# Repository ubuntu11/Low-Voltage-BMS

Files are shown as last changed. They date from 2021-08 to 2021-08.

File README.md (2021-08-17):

# Low Voltage Battery Management System with AFE(BQ76920) and Microcontroller (TM4C123GH6PM)
This is a hardware and software development of a low voltage battery management syetem, which is mainly designed for our autonomous BEV and self-driving car. However, it could also be applied to other electric devices which need an monitoring system for low voltage battery.

**LV-BMS version 1 PCB:**
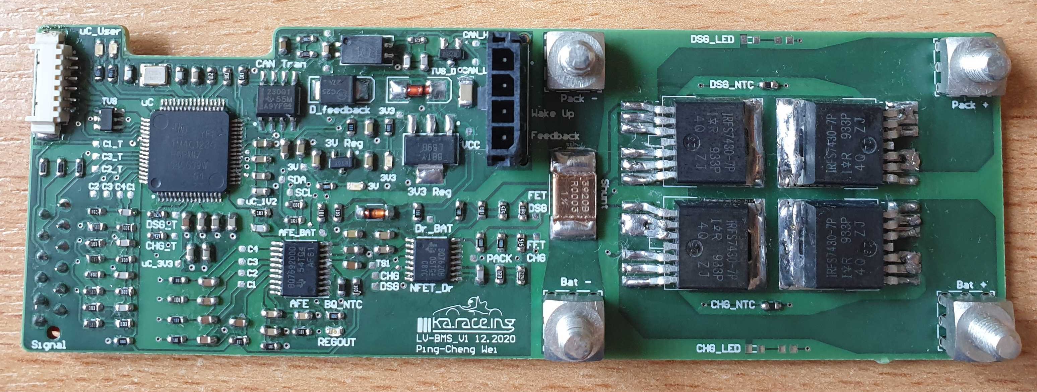
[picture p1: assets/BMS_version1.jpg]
LV-BMS version 1 PCB


The repository includes:
* The Altium PCB design of LV-BMS with either low-side MOSFET switch control(version 2) or high-side(version 3).
* Source code for the microcontroller based on C++, which is compatible for all version(1~3) design, and is written and exploited in Code Composer Studio.
* Texas Instruments TivaWare Peripheral Driver Library for the control of microcontroller. [datasheet](https://www.ti.com/lit/ug/spmu298e/spmu298e.pdf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)

## Table Of Contents
* [Concept and Functionality of the LV-BMS](https://github.com/PingCheng-Wei/Low-Voltage-BMS#concept-and-functionality-of-the-lv-bms)
* [Development of Hardware Part](https://github.com/PingCheng-Wei/Low-Voltage-BMS#development-of-hardware-part)
    * [Components & Datasheets](https://github.com/PingCheng-Wei/Low-Voltage-BMS#components--datasheets)
    * [Explaination of the Functionality in each Part](https://github.com/PingCheng-Wei/Low-Voltage-BMS#explaination-of-the-functionality-in-each-part)
        * [Analog Front End](https://github.com/PingCheng-Wei/Low-Voltage-BMS#analog-front-end-afe)
        * [I2C Communication](https://github.com/PingCheng-Wei/Low-Voltage-BMS#i2c-communication)
        * [FET Driver](https://github.com/PingCheng-Wei/Low-Voltage-BMS#fet-driver)
        * [Analog to Digital Converter](https://github.com/PingCheng-Wei/Low-Voltage-BMS#analog-to-digital-converter-adc)
    * [Altium PCB Design](https://github.com/PingCheng-Wei/Low-Voltage-BMS#altium-pcb-design)
* [Concept of Software Part](https://github.com/PingCheng-Wei/Low-Voltage-BMS#concept-of-software-part)
    * [Enviroment and Library](https://github.com/PingCheng-Wei/Low-Voltage-BMS#enviroment-and-library-datasheet)
* [Installation](https://github.com/PingCheng-Wei/Low-Voltage-BMS#installation)

# Concept and Functionality of the LV-BMS
The main idea that we need a battery management system is that lithium battery has a higher energy density, higher efficiency and lighter weight in comparison with other art of battery such as LiFePo4, which is crucial in our case to gain better performence, but it could also be life-threatening when something goes wrong. Therefore, we need a monitoring system, BMS, to keep supervising the status of the lithium battery stack during the execution of whole system and take defensive action if it is needed. The status at here means the `voltages`, `current` and `temperatures` of the battery stack. To be more specific, voltages could be the `cell voltages` as well as the `entire voltage` and current is the `entire current` that flows out the battery stack and temperatures could be the `cell temperatures` as well as the `MOSFETs' temperatures`. 

BMS monitor these three status to make sure they are all operating in the acceptable range. if not, then BMS will cut off the power supply of the whole system (LV-Battery) by switching the MOSFETs to off so that no further damage could happen and if the stutas are back to normal again, then BMS will turn on the power suppy again.

# Development of Hardware Part
The general structure of the hardware PCB design is based on the following functional parts:

* `Analog Front End (AFE)`, which is mainly responsible for collecting the parameters of the battery pack such as voltages, current as well as temperatures by using internal ADC measures. It could also control the current between the cells in order to avoid overloading and underloading, which is called cell-balancing. At here we pick [BQ76920](https://www.ti.com/lit/ds/symlink/bq76920.pdf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) from TI as our AFE since it has not only all the basic features that we need but also some other extra features e.g. hardware protection features, charge/discharge low-side NCH FET drivers, alert interrupt to host microcontroller, simple I2C compatible interface (CRC option)

* `Inter-Integrated Circuit (I2C) Interface`, which is really crucial to realize the communication between our host microcontroller (uC), `TM4C123GH6PM`, and AFE ,`BQ76920`. Through the I2C communication, uC can read value from AFE register, send commmed to AFE or even write value into the register in AFE and AFE can also sent alert to uC so that uC could take an action to deal with the errors

* `Microcontroller (uC)`, which is like the brain of the system and where we flash our code into in order to realize all the functions that we need. Here is `TM4C123GH6PM` chosen as our uC because it has lots of features to utilize and there is also a compatible [Peripheral Driver Library](https://www.ti.com/lit/ug/spmu298e/spmu298e.pdf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) on hand.

* `FET Driver`, which is needed if we want to have a high-side switch control feature according to our AFE, BQ76920, and provides the advantages of avoiding ground disconnection in the system and continuous communication between the battery pack and host system. Here [BQ76200](https://www.ti.com/lit/ds/symlink/bq76200.pdf?ts=1629016585303&ref_url=https%253A%252F%252Fwww.google.com%252F) is chosen as it is directly competible and circuit design is also provide in both [BQ76200](https://www.ti.com/lit/ds/symlink/bq76200.pdf?ts=1629016585303&ref_url=https%253A%252F%252Fwww.google.com%252F) and [BQ76920](https://www.ti.com/lit/ds/symlink/bq76920.pdf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) datasheet.

    Here is an overview of how BQ and uC structured:
    
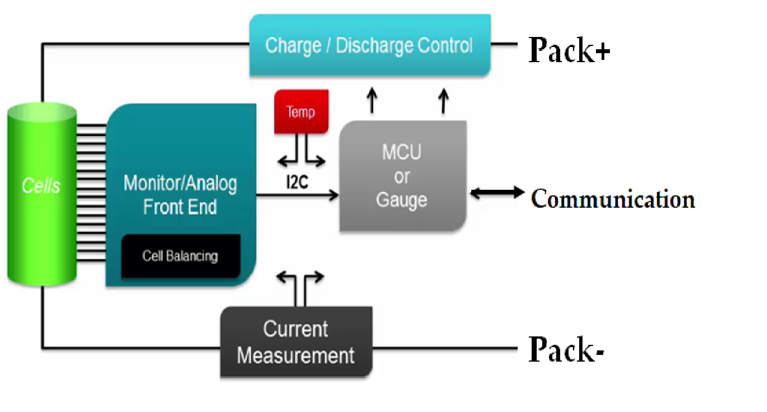
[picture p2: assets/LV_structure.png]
overview of BQ-chip
    

Other features that we need for our autonomous BEV and self-driving car:
* `CAN Bus system`, which is a communication system between our uC and centeral `main control unit (MCU)` in our cars so that MCU could know what is going on right now in LV-system and whether every thing is fine. For some cases, MCU could even take some preventative steps to protect the car if something in LV-system goes wrong.
* `Analog to digital converter (ADC) in uC`, which is exploited for more temperatures monitoring such as Battery stack temperatures and MOSFETs' temperatures.

## Components & Datasheets
You could find all the components and their footprints that are utilized on the PCB in the [Bill of Materials (BOM)](https://github.com/PingCheng-Wei/Low-Voltage-BMS/blob/main/assets/BOM_LV_21E.xlsx). Here we just list the most important components:

* Microcontroller: [TM4C123GH6PM](https://www.ti.com/lit/ds/spms376e/spms376e.pdf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)
* Analog Front End: [BQ76920](https://www.ti.com/lit/ds/symlink/bq76920.pdf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) without CRC
* FET Driver: [BQ76200](https://www.ti.com/lit/ds/symlink/bq76200.pdf?ts=1629016585303&ref_url=https%253A%252F%252Fwww.google.com%252F)
* MOSFETs: [AUIRFS8409-7P](https://www.infineon.com/dgdl/auirfs8409-7p.pdf?fileId=5546d462533600a4015355b745e314f0)
* 3.3V CAN Bus Transceivers: [SN65HVD230](https://www.ti.com/lit/ds/symlink/sn65hvd230.pdf?ts=1628607753622)

Other useful datasheets for more understanding of the circuit design:
* BQ relevant:
    * [bq76200 Beyond the Simple Application Schematic](https://www.ti.com/lit/an/slua794/slua794.pdf?ts=1629017183044&ref_url=https%253A%252F%252Fwww.google.com%252F)
    * [FET Configurations for the bq76200 High-Side N-Channel FET Driver](https://www.ti.com/lit/an/slva729a/slva729a.pdf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)
    * [bq769x0 Family Top 10 Design Considerations](https://www.ti.com/lit/an/slua749a/slua749a.pdf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)
    * [10s battery monitoring, balancing, and comp protection, 50A discharge ref design](https://www.ti.com/lit/ug/tiduar8c/tiduar8c.pdf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)
    * [bq769x0 BMS Configurations for Cordless Appliances](https://www.ti.com/lit/an/slua810/slua810.pdf?ts=1628994785378)

* I2C relevant:
    * [Understanding the I2C Bus](https://www.ti.com/lit/an/slva704/slva704.pdf?ts=1629009658472&ref_url=https%253A%252F%252Fwww.google.com%252F)
    * [I2C Communication Sample Code for the bq76940 with a CRC Option Based on the MSP430G2553](https://www.ti.com/lit/an/slva626b/slva626b.pdf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)

* Microcontroller relevant:
    * [MCU_tm4c123gh6pm](https://www.ti.com/lit/ds/spms376e/spms376e.pdf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)
    * [TivaWare Peripheral Driver Library Users's Guide](https://www.ti.com/lit/ug/spmu298e/spmu298e.pdf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)

## Explaination of the Functionality in each Part
### Analog Front End (AFE)
As described above, we use an AFE, BQ76920, to realize the parameters monitoring and MOSFETs control. Here we would like to explain more about the funtionality behind `BQ76920`. It is also helpful to go deep into datasheet as it not only provides you a better overview of hardware but also better understanding of the algorithm in software code.

BQ76920 is a pre-programmed chips that already has the function like voltages, current and temperatures measurement and it would automatically keep monitoring/update the value in a certain amount of time. If something goes wrong, the internal system status will be set to bit 0 and automatically disable the charge and discharge control (CHG & DSG Pins set to 0). Therefore, in order to use BQ76920, it is rather important to grasp the concept of how to let microcontroller communicate with the BQ's register and control the BQ's status through I2C than understand how internal measurement works. here is an important system status of BQ76920 in register:
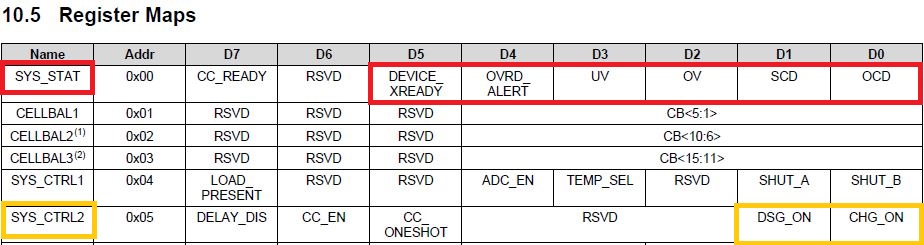
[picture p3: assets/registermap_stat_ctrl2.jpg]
status in register map


Take cell voltages measurement for example, `it update the cell voltages at a rate of 250 ms` and store the value inside its register for other functions utiliztion such as overvoltage and undervoltage check. This means that if BQ76920 updates the voltage and finds out they are out of the limit range, it will internally set the corresponding system status to 0 (means error) and since system status are not all 1, it will then automatically turn off the power supply by shuting down the CHG or DSG Pin to bit 0, which is bit 1 (means on) when everything is fine, and send a alert signal to our microcontroller. This all happen in BQ internally by itself. Thus, you might wonder why we need a microcontroller then if everything works internally. The reason is that we need a microcontroller to clear the alert/error bit. By that it means that microcontroller will keep demanding the BQ to update its system status, in this case keep measuring the cell voltages, and until the voltages are back into acceptable range microcontroller can then successfully clear the alert/error bit and BQ would then allow the charge or discharge control by setting CHG or DSG Pin to bit 1.

### I2C Communication
In order to grasp the deep understanding of how I2C works, it is highly recommanded that you go through and deep into this article "[Understanding the I2C Bus](https://www.ti.com/lit/an/slva704/slva704.pdf?ts=1629009658472&ref_url=https%253A%252F%252Fwww.google.com%252F)". In the article you should understand how I2C recognize the start as well as the end bit from SCL (Serial Clock) & SDA (Serial Data) and how the signals are read. Here we would like to show some I2C signal from Oscilloscope:

* overview:
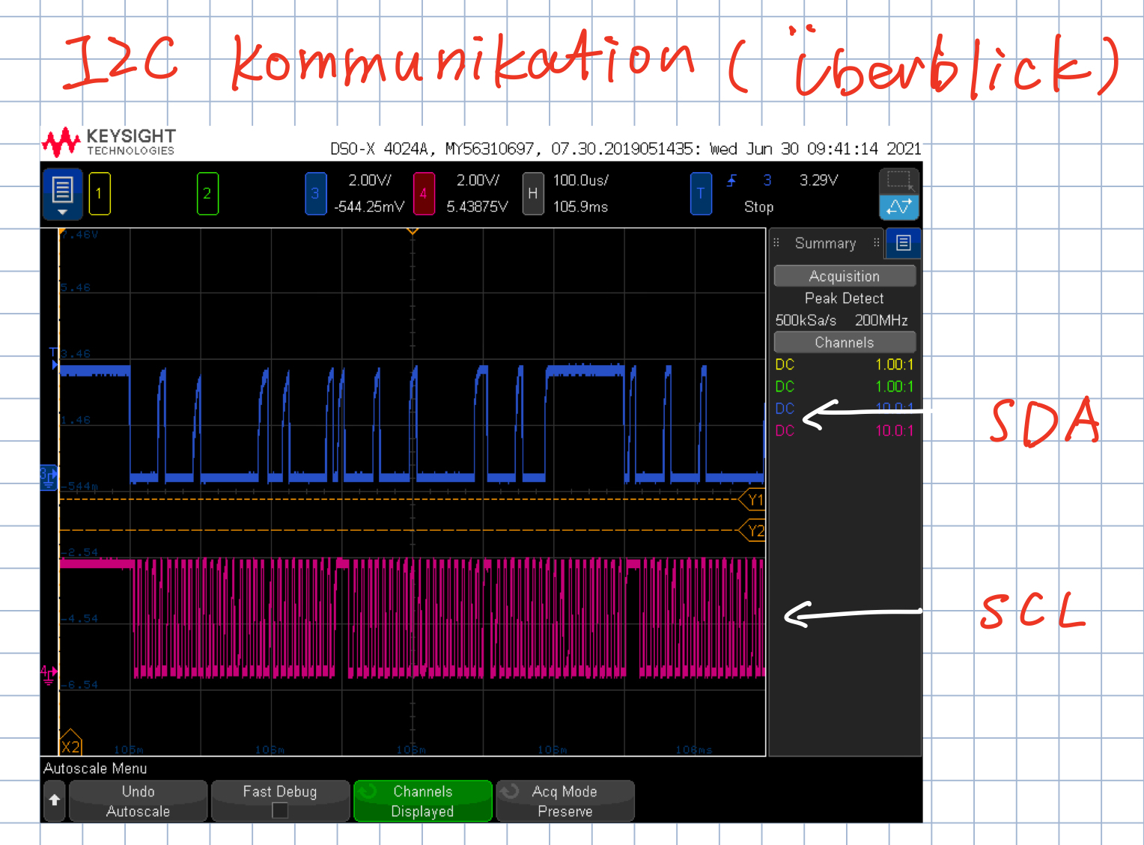
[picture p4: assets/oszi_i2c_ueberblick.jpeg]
oszi_i2c_overview
    
* I2C Signal:
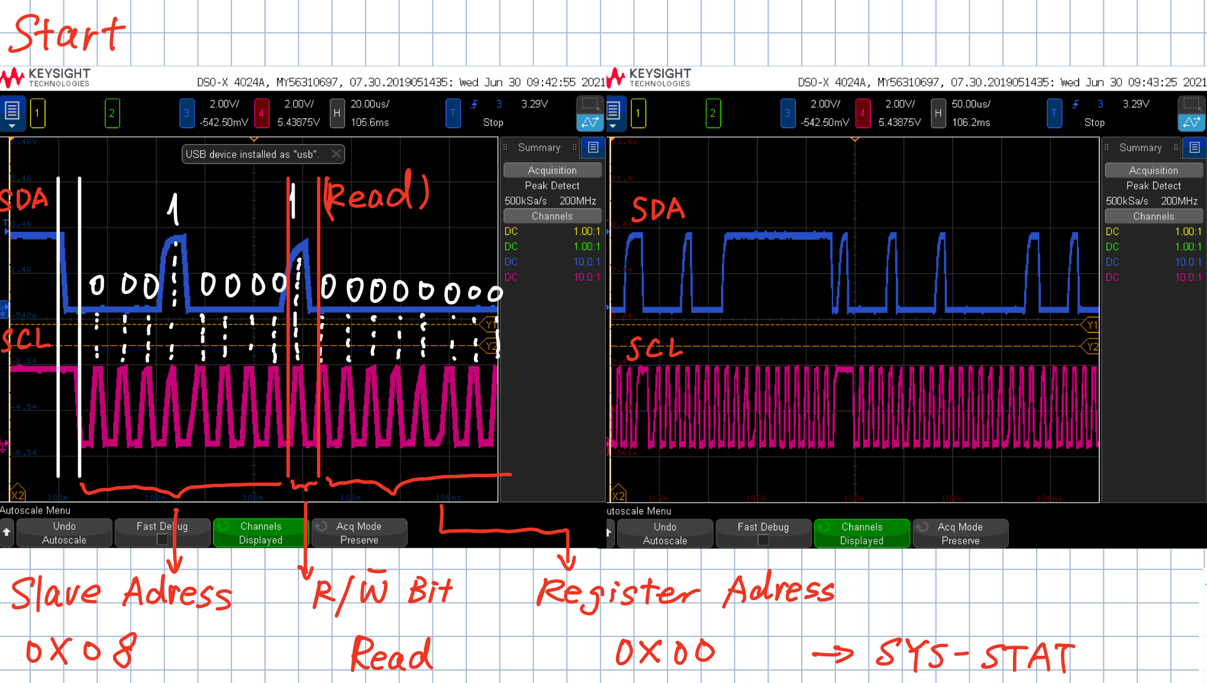
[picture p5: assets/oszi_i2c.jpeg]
oszi_i2c_signal
    

### FET Driver
As mentioned above, BQ76920 itself only support the low-side switch feature. However, in some cases it would benefit more if we would able to use high-side switch. That is why we need a FET Driver to convert the signal of CHG/DSG from BQ76920 to higher voltage. The idea behind [BQ76200](https://www.ti.com/lit/ds/symlink/bq76200.pdf?ts=1629016585303&ref_url=https%253A%252F%252Fwww.google.com%252F) is using a `charge pump capacitor`, which works like an extra small battery connected in series with low-voltage battery, as you could see in the circuit example `between the VDDCP and BAT pins`. During the operation the charge pump capacitor will keep charging and discharging process to store and release the energy. By doing so we could raise our gate-voltage of MOSFETs to surpass the source-voltage of MOSFETs, which is same as low-voltage battery voltage, and achieve a positive gate-source-voltage to turn on the high-side MOSFETs. 

Here is how the voltage from CHG and DSG changes after the FET driver:
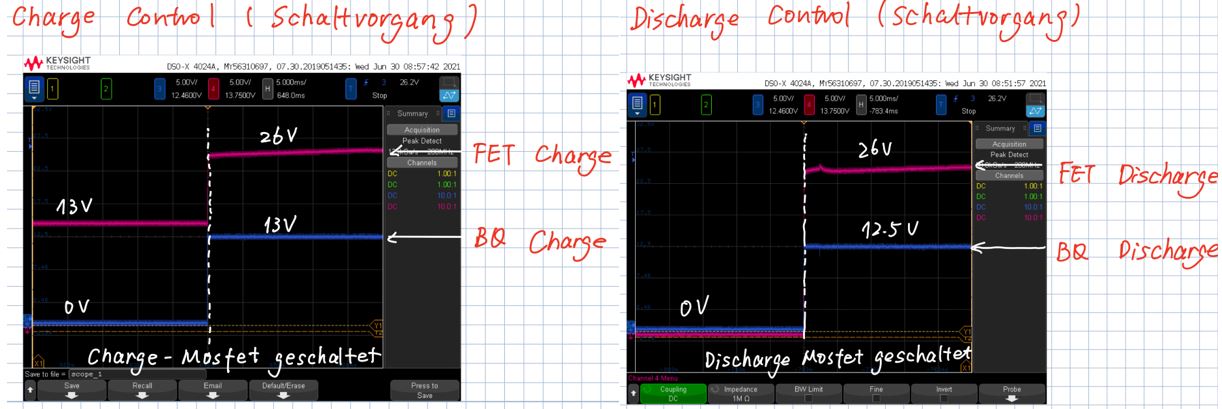
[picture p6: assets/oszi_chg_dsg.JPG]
oszi_chg_dsg


It is also interesting to see the charging and discharging process in charge pump capacitor:
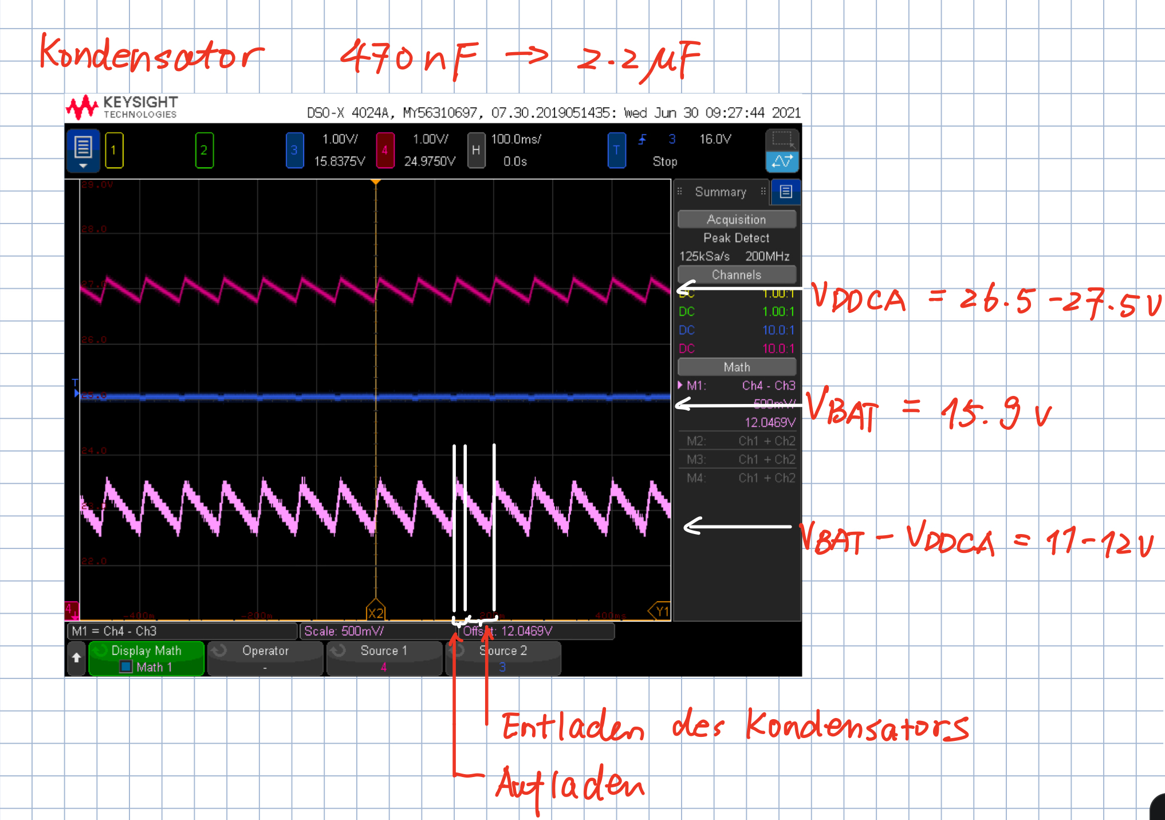
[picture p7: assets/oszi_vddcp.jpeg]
oszi_vddcp


If everything works fine the `gate-source-voltage` of the MOSFETs would looks like this:
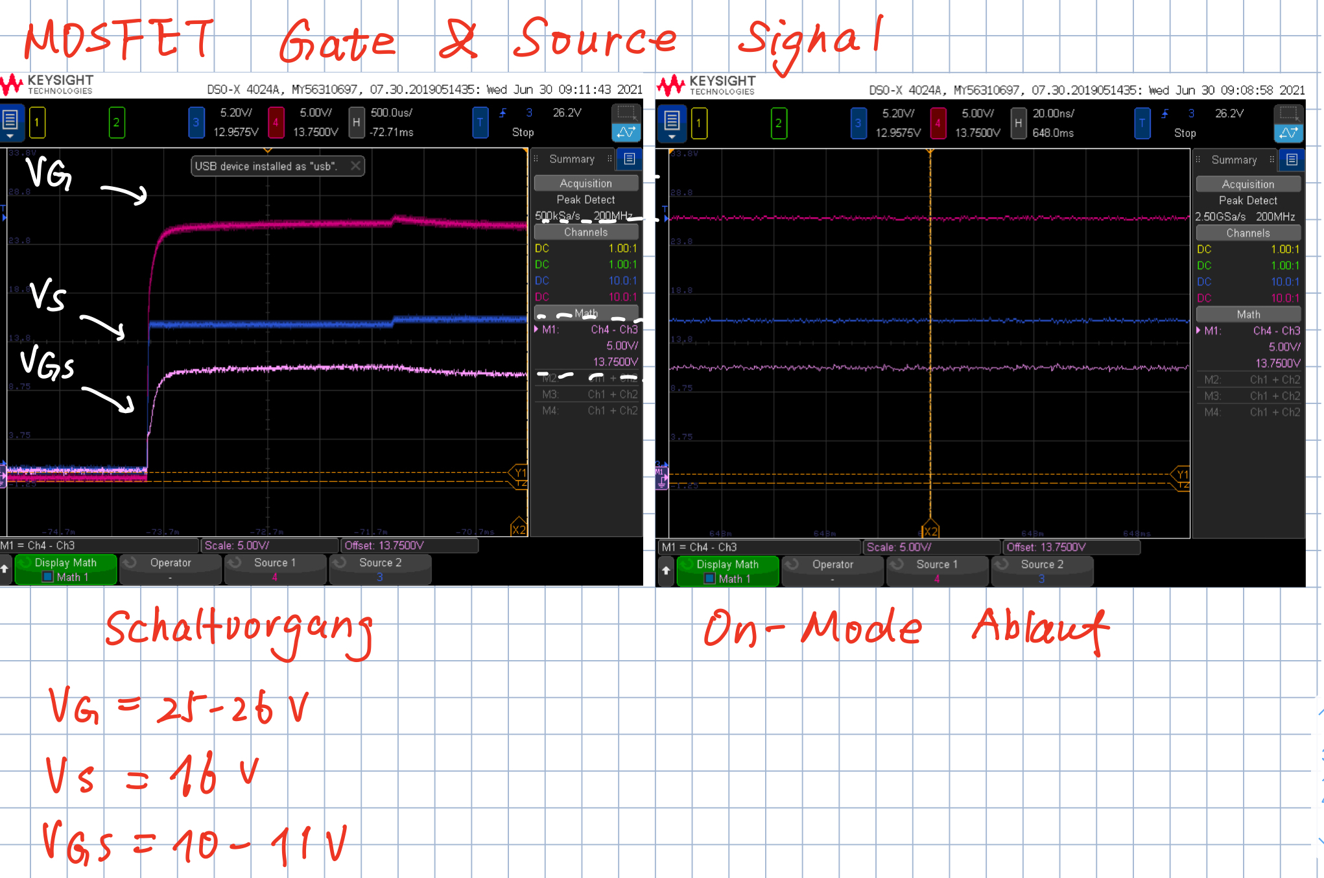
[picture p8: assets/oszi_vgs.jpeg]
oszi_vgs


`Here is the capacity of the charge pump capacitor very critical !!!` If the value is too small, then the capacitor can't store enough energy and it will soon be all released, which leads to just some peaks of higher voltage as the images below show:

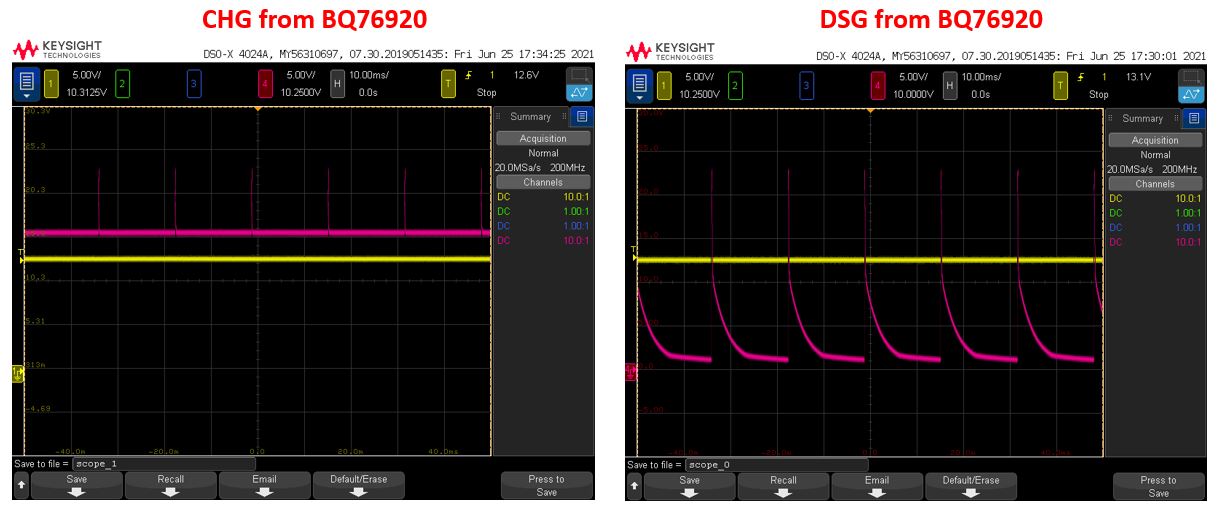
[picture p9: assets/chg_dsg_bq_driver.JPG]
chg_dsg_bq_driver


If the capacity is too big, then the capacitor does not have enough time to reach the needed energy since the charging rate is too low. Therefore, `after several testing we have chosen $2.2 uF$ instead of $470nF$ according to datasheet`.

### Analog to Digital Converter (ADC)
Since the microcontroller can't understand the analog value such as 3.3V or 1A and its internal measurement only send back a bit by bit signal e.g. in a range of 0 ~ 4096 corresponding to 12 bits signal, we need to convert/calculate this bit by bit signal back to the corresponding analog value range and we will recieve the so called digital value. Here is the general equation of ADC:
    
ADC_equation

For example if we have the following situation:
* ADC signal bit length: 12 bits
* Voltage range: 0 ~ 4.3V
* ADC measured value: 3000 

then our converted digital value would be:
    
ADC_calculation

which means the measured ADC valus 3000 is corresponding to 3.15V.

## Altium PCB Design
Generally, we have 4 functional parts: `Microcontroller (TM4C)`, `Analog Front End (BQ76920)`, `FET driver (BQ76200)`, `MOSFETs` for power contro.
We place it in such a way that the analog part, digital part, power part are as separated as possible from each other so that we have cleaner signals. As the image below shown, which is based on LV-BMS version 1, you can see that the polygons are divided into 3:

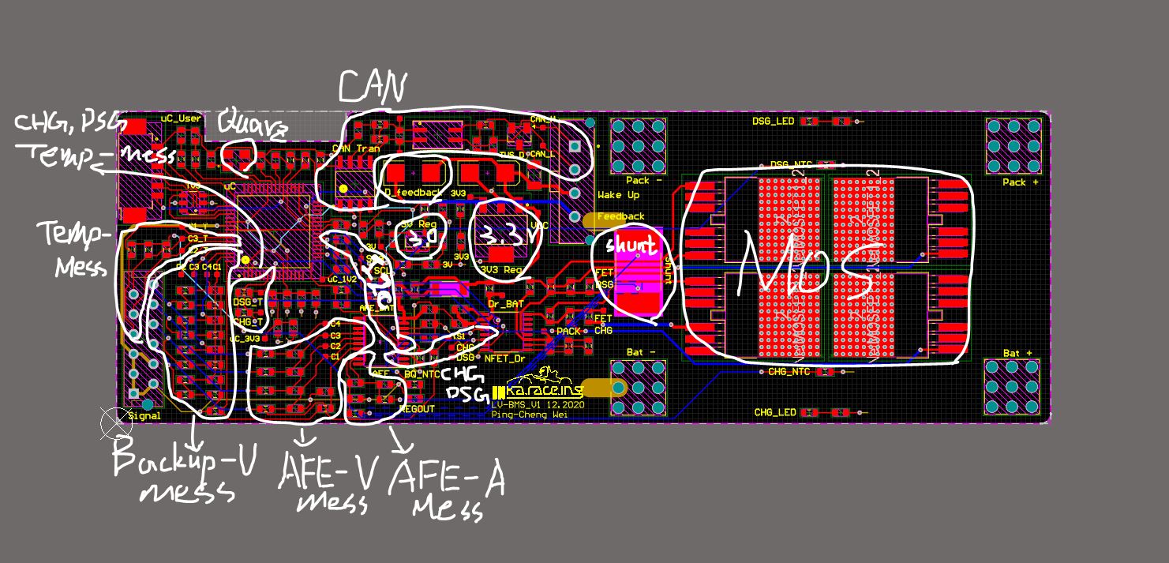
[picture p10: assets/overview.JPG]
overview of PCB design


Polygons and netz distribution based on LV-BMS version 1:
| Net von Polygons | Analog Part  | Digital Part  | Power Part |
| --- | ---  | ---  | --- |
| Top Layer | GND | GND | (komplizierter) |
| GND Layer | GND | GND | GND |
| VCC Layer | V_REF (3.0V) | +3.3V | Bat + |
| Bottom Layer | GND | GND | GND |

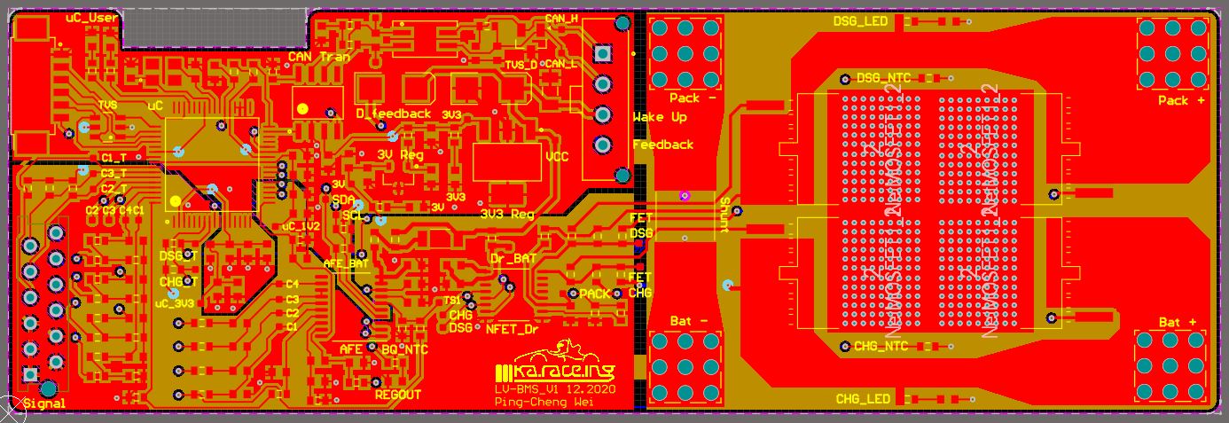
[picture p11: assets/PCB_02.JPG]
Polygons of PCB design


# Concept of Software Part
We have created our header files and source files based on following different functions we needed:

* `ADC`: enable the ADC function in microcontroller and include the convert voltage and temperature functions for monitoring
* `I2C`: create a `bq769x0 class` for AFE (BQ) and enable I2C communication with microcontroller
* `Timer`: create timer interrupt to percisely call a function at a certain rate and percise delay function, which is better then using SysCtlDelay(5000000)
* `GPIO`: General Purpose Input/Output, to enable or activate the pins on microcontroller and set the pin as input or output (3.3V)
* `CANDriver`: create a basic CAN class including basic CAN bus initialization and communication functions like sending and receiving messages
* `TestCAN`: inherit from CANDriver class. This builds the structure of our CAN message in byte level.

The main idea of code is to update BMS status at the rate of $250mS$ to monitor the voltages, current and temperatures. Therefore, we have created a `GlobalBMSUpdate` function and a timer interrupt to percisely call this function at this rate. For our AFE/BQ-chip, we have created a class for it, which has lots of features such as **current status, min/max limit of each status and BQ slave adress** and functions like **I2C communication, set values, get current status values, update status and enable charging/discharging**. By doing so, you could design a LV system with even more BQ-chips by create more BQ objects and don't need to worry about the code being messy as well as confused. However, we just create 1 BQ object as we only need 1 BQ76920 in our case. This BQ class also support other chips in BQ769x0 family, which could monitor more voltages and temperatures. 

Additionaly, we have enabled the ADC function in microcontroller since our microcontroller has lots of features and we want more ADCs to monitor more temperatures and utilize for backup voltages in case BQ is somehow not working.

Overall steps and ideas in main function (main.cpp):
1. Include all libraries and header files we needed
2. Create BMS object as global variable, `BMS`
3. Define global BMS update function, `GlobalBMSUpdate()`, for `TimerBMSUpdatesInterruptBegin()` function
4. Set up system clock & Initialization of all TM4C Systems (GPIO, ADC, Timer, CAN)
    * Set up system clock at 80 MHz
    * By GPIO is mainly focusing on port enabling from TM4C (Port A-F) and also Pin type for FET Driver and LED
    * By ADC are all the necessary settings for ADC measurement such as ADC 1,2 , sample sequence, step configuration, ADC enable
    * Start the `TimerDelayInterruptBegin()` function so that we could have a precise delay for later use
    * Set up the rx_pin, the tx_pin, and the rate for CAN
5. Enable charge pump and pack+ monitor for FET Driver
6. Initialize the I2C/BQ-chip (AFE) from `BMS`
    * `Enable I2C Communication !!!!!`
    * Initialize all the temperature and voltage buffer
    * Boot up BQ-Chip by outputting 3.3V from a GPIO Pin of TM4C for just a short time (around 2ms) ⇒ BQ always need an Activation at first before it starts working (change from SHIP mode to NORMAL mode)
    * Test I2C functionality by trying to write (I2CWriteRegister) something in the register of BQ and checking the equality from reading the register (I2CReadRegister)
        * If communication succeed, enable I2C voltage and temperature ADC readings and switch CC_EN on
    * Initialize and set up the alert interrupt IRS (GPIO_RISING_EDGE interrupt)
    * Get the ADC offset and gain
7. `BMS` system set up
8. Call the `TimerBMSUpdatesInterruptBegin()` function to run the GlobalBMSUpadate, which would enable CHG and DSG simultaneously, in each 250 second
9. Activate the ADC function in uC to read the temperatures
10. check the Temperature status. if too high, then BMS shutdown the battery
11. Send out the message through the CAN bus to let our `Main Control Unit` in car know the status of LV system

_For more information and understanding, explore yourself in the code, which is pretty well commented. The main and biggest part of the code is the I2C part ( [I2C.hpp](https://github.com/PingCheng-Wei/Low-Voltage-BMS/blob/main/Software_Code/LV-BMS_Code/include/I2C.hpp) & [I2C.cpp](https://github.com/PingCheng-Wei/Low-Voltage-BMS/blob/main/Software_Code/LV-BMS_Code/src/I2C.cpp) )_

## Enviroment and Library (datasheet)
* Code written in C++
* Code Composer Studio (CCS) with setting of `TM4C123GH6PM` microcontroller for flashing
* TivaWare Peripheral Driver Library

# Installation 
1. Clone this repository

    if you download this repository directly without any changing, your directory should have the following structure:

    ```
    <dataset root directory (e.g. Low-Voltage-BMS)>/
    assets/
    Hardware_PCB_Design/
        LV-BMS_high-side/
            ...
            LV-BMS_21_V2.PrjPcb
            LV-BMS_V2_21E.PcbDoc
            ...
        LV-BMS_low-side/
            ...
            LV-BMS_21_V3_low-side.PrjPcb
            LV-BMS_V3_21E_low-side.PcbDoc
            ...
    Software_Code/
        LV-BMS_Code/
            ...
        tidriverlib-master/ 
            ...
    ```

    Please keep the Software part structure as it is, otherwise it won't work in CCS unless you change the path to where you put the `tidriverlib-master` !!!

2. Download Altium and activate a licence in order to use it 
    * imoprt all the schematic libraries, PCB libraries and compiled libraries of the conponents from `Component Footprint Import` directory. Please check out online tutorials to see how to import Footprint from integrated libraries (`.IntLib`), schematic libraries (`.SchLib`) and PCB libraries (`.PcbLib`) or check this links: [Working with Integrated Libraries in Altium Designer 2021](https://www.altium.com/documentation/altium-designer/working-with-integrated-libraries-ad?version=17.1), [Working with Integrated Libraries in Altium Designer 2020](https://www.altium.com/documentation/altium-designer/working-with-integrated-libraries-ad)
    
    * Here are some useful links to download and import your own footprint of components you needed
        * [Free Online PCB CAD Library | Ultra Librarian](https://www.ultralibrarian.com/)
        * [Import the downloaded Ultra Librarian files into Altium Designer](https://app.ultralibrarian.com/content/help/?altium_designer.htm)

    * In order to open the PCB project, click the file with  `.PrjPcb` extension. This will automatically open all the schematics and PCBs file which belong to the Project.
        ```
        For instance: LV-BMS_21_V2.PrjPcb
        ```

3. Download Code Composer Studio
    * Set the microcontroller to `TM4C123GH6PM`
    * Make sure the path to the TivaWare Peripheral Driver Library (`tidriverlib-master`) is correctly pointed to in the properties of the project. Right click on the `KIT21_LVBMS_Code` and then go to `Properties`. Do the followings:
        * Go to `CCS Build -> ARM Compiler -> Include Options`
            ```bash
            # Make sure this exists on the top of the first block (Add dir to #include search path) 
            ${PROJECT_ROOT}\..\tidriverlib-master

            # If it's not, add this line by clicking "Add..." on the top right corner to add the library path and also move it up to the top/first one by clicking "Move Up"
            ${PROJECT_ROOT}\..\tidriverlib-master

            # If you have change the path of "tidriverlib-master", please add a relative path from project root to where your "tidriverlib-master" is, such as:
            ${PROJECT_ROOT}\relative\path\to\tidriverlib-master
            ```
        * Go to `CCS Build ->  ARM Linker -> File Search Path`
            ```bash
            # Make sure this exists on the top of the first block (Include library file or command file as input) 
            ${PROJECT_ROOT}\..\tidriverlib-master\driverlib.lib

            # If it's not, add this line by clicking "Add..." on the top right corner to add the library path and also move it up to the top/first one by clicking "Move Up"
            ${PROJECT_ROOT}\..\tidriverlib-master\driverlib.lib

            # If you have change the path of "tidriverlib-master", please add a relative path from project root to where your "tidriverlib-master" is, such as:
            ${PROJECT_ROOT}\relative\path\to\tidriverlib-master\driverlib.lib
            ```
    * Right click on the `KIT21_LVBMS_Code` and then go to `Properties`. Go to `CCS Build ->  ARM Linker -> Basic Options` and find `Set C system stack size`. Make sure the `system stack size` is greater than or at least `2048` ! Otherwise it can't successfully flash the code due to insufficient memory issue

4. There you are, done! Feel free to explore yourself and change the Hardware design or software code to your need

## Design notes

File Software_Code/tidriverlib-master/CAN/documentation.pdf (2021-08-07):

## CAN Treiber

Generated by Doxygen 1.8.13

# Contents

# Chapter 1

# Class Index

## 1.1 Class List

Here are the classes, structs, unions and interfaces with brief descriptions:

CANDriver
CAN Treiber | ??

### 2 Class Index

Generated by Doxygen

# Chapter 2

# Class Documentation

## 2.1 CANDriver Class Reference

CAN Treiber.

#include "CAN/CANDriver.hpp"

Public Member Functions

- void init (CAN0Rx rx_pin, CAN0Tx tx_pin, uint32_t baudrate)

CAN0 Initialisierungsfunktion.
- void init (CAN1Rx rx_pin, CAN1Tx tx_pin, uint32_t baudrate)

CAN1 Initialisierungsfunktion.
- bool checkStatusInterrupts (void)

Ueberprueft den Status des Treibers.
- uint32_t getMessageInterruptMask (void)

Checkt ob neue Nachrichten empfangen wurden.
- tCANMsgObject getMessage (uint32_t postbox)

Gibt Inhalt der als Parameter uebergebenen Postbox zurueck.

Protected Member Functions

- void sendCANMessage (tCANMsgObject ∗txCANMsg, uint32_t postbox)

Funktion zum senden von CAN Nachrichten.
- virtual void registerReceiveMessages (void)

Registrieren der CAN Nachrichten, die gelesen werden sollen.

Protected Attributes

- tCANMsgObject txMessage
- CAN_BASE can_base
- tCANMsgObject rxMessage

### 4 Class Documentation

### 2.1.1 Detailed Description

CAN Treiber.

Diese Klasse kann als Treiber fuer die CAN Kommunikation in Verbindung mit dem TM4C123GH6PM genutzt werden. Es stehen 32 Postboxen zur Verfuegung. Von dieser Klasse sollte immer eine Tochterklasse erstellt werden und damit gearbeitet werden. Bitte diese Klasse nicht editieren oder nur nach Absprache mit STL.

### 2.1.2 Member Function Documentation

### 2.1.2.1 checkStatusInterrupts()

bool CANDriver::checkStatusInterrupts (

void )

Ueberprueft den Status des Treibers.

Ueberprueft ob Fehler vorliegen und ob das Modul in den passiven Modus gewechselt ist(es koennen keine CAN Nachrichten mehr empfangen und gesendet werden). Liegt dieser Fall vor, wird automatisch wieder in den aktiven Modus gewechselt. Sollte immer vor getMessageInterruptMask() aufgerufen werden.

### 2.1.2.2 getMessageInterruptMask()

uint32_t CANDriver::getMessageInterruptMask (

void )

Checkt ob neue Nachrichten empfangen wurden.

Gibt eine Mask zurck, die angibt, in welcher Postbox ein Interrupt aufgetreten ist. Diese Nachricht kann danach mit getMessage() gelesen werden. Zuvor sollte immer checkStatusInterrupts() ausgefuehrt werden.

### 2.1.2.3 init() [1/2]

void CANDriver::init (

CAN0Rx rx_pin,

CAN0Tx tx_pin,

uint32_t baudrate )

CAN0 Initialisierungsfunktion.

Initialisiert den Treiber fuer die uebergebenen Pins und Baudrate. Die Pins werden komplett konfiguriert, ggf. Hardware entlockt. Es wird automatisch an der Auswahl der Pins erkannt, welcher der beiden internen CAN-←-Module genutzt wird.

2.1 CANDriver Class Reference | 5

### 2.1.2.4 init() [2/2]

void CANDriver::init (

CAN1Rx rx_pin,

CAN1Tx tx_pin,

uint32_t baudrate )

CAN1 Initialisierungsfunktion.

Initialisiert den Treiber fuer die uebergebenen Pins und Baudrate Die Pins werden komplett konfiguriert, ggf. Hardware entlockt. Es wird automatisch an der Auswahl der Pins erkannt, welcher der beiden internen CAN-Module genutzt wird.

### 2.1.2.5 registerReceiveMessages()

void CANDriver::registerReceiveMessages (

void | ) | [protected], [virtual]

Registrieren der CAN Nachrichten, die gelesen werden sollen.

Diese Funktion ist hier leer und sollte zur Benutzung in der Tochterklasse ueberschrieben werden. Pro Nachricht die empfangen werden soll wird eine Postbox benoetigt. Insgesamt gibt es 32 Postboxen. Es kann keine Postbox zum Senden und Empfangen genutzt werden.

### 2.1.2.6 sendCANMessage()

void CANDriver::sendCANMessage (

tCANMsgObject ∗ txCANMsg,

uint32_t postbox ) [protected]

Funktion zum senden von CAN Nachrichten.

Mit dieser Funktion kann eine Nachricht in eine Postbox platziert werden, die dann automatisch versendet wird. Wenn moeglich, sollte eine Postbox jeweils nur fuer eine Nachricht genutzt werden, um nicht gewuenschte Ueberschreibungen in der Postbox zu vermeiden. Auch darf keine Postbox gewaehlt werden, die bereits zum Empfangen von Nachrichten genutzt wird. Insgesamt gibt es 32 Postboxen.

The documentation for this class was generated from the following files:

- D:/KaRaceing/Software/KIT18/TIDriverlib/CAN/CANDriver.hpp
- D:/KaRaceing/Software/KIT18/TIDriverlib/CAN/CANDriver.cpp

### 6 Class Documentation

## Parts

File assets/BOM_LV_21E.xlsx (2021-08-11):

Component | Manufacture number | Footprint | Amount | Description | Datasheet
Input / Output Signal
3.3-V CAN Bus Transceivers | SN65HVD230D | D0008A_M | 1 | CAN Bus Transceiver, 3.3 V, -40 to 85 degC, 8-Pin SOIC (D), Green (RoHS & no Sb/Br), Tube
WE-SLM Drosselspule | 744242101 | WE-SLM | 1 | SMD Common Mode Line Filter WE-SLM, L = 100 µh
TVS Diodes | 824022 | SOT23_3L | 1 | ESD Suppressors / TVS Diodes WE-TVS Standard 2.5uA 5VDC 2Channel
THT Male Header WR-MPC3 | 66200411122 | 66200411122 | 1 | THT Male Header WR-MPC3, Vertical, Single Row, pitch 3 mm, 4 pins
Female THT Straight Connector | 690367181272 | 690367181272 | 1 | Headers & Wire Housings WR-MM 1.27mm Female 12Pin w/oLtch/Plztn
Male THT Straight Connector | 690157001272 |  |  | Headers & Wire Housings WR-MM 2.54mm IDC 12Pins Male Red
Diode |  | SMB | 1
Power_Supply Voltage
3.3V Low Dropout Voltage Regulator | LM2937IMP-3.3/NOPB | DCY0004A_M | 1 | 400mA and 500mA Voltage Regulator, 4-pin SOT-223, Pb-Free
3.0V CMOS Voltage Reference | REF3030AIDBZR | DBZ0003A_L | 1 | 3.0 V, 50 ppm / degC, 50 uA Series (Bandgap) Voltage Reference, -40 to 125 degC, 3-pin SOT-23 (DBZ), Green (RoHS & no Sb/Br)
LED |  | 1608[0603] | 2
Zener Diode |  | SMB | 1
AFE_BQ-Chip
AFE Cell battery monitor | BQ7692000PW | PW0020A_N | 1
high-side NFET driver | BQ76200PW | PW0016A_N | 1
Shunt Widerstand | LRMAP3920B-R0003FT | RES_LRMAP3920B-R0003FT_WEL | 1 | 300uR
Grund Pillar | 7461096 | 7461096_for chemical surfaces | 4 | WP-SHFU Press-Fit with External thread, full plain, 7x7mm, 9 pins, M4x6mm, 130A
Small Signal Fast Switching Diodes | LL4148GS08 | MELF_SOD-80_VIS | 1
Thermistor |  | J1-0603 | 1 | 10kR
Power MOSFET | IRFS7430TRL7PP | D2PAK_TO-263AB_INF | 4
Microcontroller
Microcontroller | TM4C123GH6PMT | PM0064A_L | 1 | Tiva C Series Microcontroller, 256 KB Flash, 32 KB SRAM, 12 Bit, 12 Channels, -40 to 105 degC, 64-Pin LQFP (PM), Green (RoHS & no Sb/Br)
WE-XTAL 16MHz Quartz Crystal, 830108207109 | LFXTAL082069Reel | WE-XTAL_CFTX-180 | 1 | WE-XTAL Quartz Crystal, SMT, CFPX-180, 16MHz, +/-10ppm
SMT Male Horizontal Shrouded Header | 653106131822 | 653106131822 | 1 | Male Shrouded Header WR-WTB, SMT, Right Angled, pitch 1.25 mm, 1 x 6 position
Thermistor |  | J1-0603 | 2
LED |  | 1608[0603] | 2
Resistor |  | J1-0603
Capacitor |  | C1206 | 1
Capacitor |  | 1608[0603]
Jumper |  | J1-0603

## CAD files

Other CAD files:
Software_Code/LV-BMS_Code/Debug__TI/main.obj
Software_Code/LV-BMS_Code/Debug/src/Timer.obj
Software_Code/LV-BMS_Code/Debug__TI/src/TestCAN.obj
Software_Code/LV-BMS_Code/Debug/src/GPIO.obj
Software_Code/LV-BMS_Code/Debug__TI/src/CANDriver.obj
Software_Code/LV-BMS_Code/Debug__TI/tm4c123gh6pm_startup_ccs.obj
Software_Code/LV-BMS_Code/Debug/src/ADC.obj
Software_Code/LV-BMS_Code/Debug__TI/src/I2C.obj
Software_Code/LV-BMS_Code/Debug/src/I2C.obj
Software_Code/LV-BMS_Code/Debug__TI/src/GPIO.obj
Software_Code/LV-BMS_Code/Debug/src/CANDriver.obj
Software_Code/LV-BMS_Code/Debug__TI/src/Timer.obj
Software_Code/LV-BMS_Code/Debug__TI/src/ADC.obj

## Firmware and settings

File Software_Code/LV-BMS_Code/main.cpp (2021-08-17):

/**
 * main.c
 */

#include <stdbool.h>
#include <stdint.h>
#include <stdio.h>
#include <string.h>
#include <math.h>

#include "inc/hw_i2c.h"
#include "inc/hw_ints.h"
#include "inc/hw_memmap.h"
#include "inc/hw_gpio.h"
#include "inc/hw_types.h"
#include "inc/hw_can.h"
#include "inc/hw_adc.h"

#include "driverlib/gpio.h"
#include "driverlib/interrupt.h"
#include "driverlib/pin_map.h"
#include "driverlib/sysctl.h"
#include "driverlib/rom_map.h"
#include "driverlib/uart.h"
#include "driverlib/timer.h"
#include "driverlib/i2c.h"
#include "driverlib/can.h"
#include "driverlib/adc.h"
#include "driverlib/ssi.h"
#include "driverlib/fpu.h"

#include <include/I2C.hpp>
#include <include/Defines.hpp>
#include <include/ADC.hpp>
#include <include/Timer.hpp>
#include <include/GPIO.hpp>
#include <include/CANDriver.hpp>
#include <include/TestCAN.hpp>



/*
 * define global variable
 */
RegisterGroup Registers;
bq769x0 BMS(bq76920, I2C_SLAVE_ADDRESS);  // BMS object

// -----------------------------------------------------------------------------------------------------------------------------
/*
 * Option 1: Just turn both CHG and DSG on by using the update function in I2C class
 */

// define global BMS update function for TimerBMSUpdatesInterruptBegin() function
void GlobalBMSUpdate(void)
{
    BMS.update(&Registers);

    // Visualization of the run of update
    GPIOPinWrite(LED_BASE, OK_LED, OK_LED);
    SysCtlDelay(5000000); // Delay(100);
    GPIOPinWrite(LED_BASE, OK_LED, 0x00);
    SysCtlDelay(5000000); // Delay(100);
}

// -----------------------------------------------------------------------------------------------------------------------------
/*
 * Option 2: Depending on which mode we are in by comparing the Bat+ and Pack+, turn on the corresponding CHG or DSG funktion
 */

// define global BMS charge update function for TimerBMSUpdatesInterruptBegin() function
void GlobalBMSUpdateCHG(void)
{
    BMS.updateCHG(&Registers);

    // Visualization of the run of update
    GPIOPinWrite(LED_BASE, OK_LED, OK_LED);
    SysCtlDelay(5000000); // Delay(100);
    GPIOPinWrite(LED_BASE, OK_LED, 0x00);
    SysCtlDelay(5000000); // Delay(100);
}

// define global BMS discharge update function for TimerBMSUpdatesInterruptBegin() function
void GlobalBMSUpdateDSG(void)
{
    BMS.updateDSG(&Registers);

    // Visualization of the run of update
    GPIOPinWrite(LED_BASE, OK_LED, OK_LED);
    SysCtlDelay(5000000); // Delay(100);
    GPIOPinWrite(LED_BASE, OK_LED, 0x00);
    SysCtlDelay(5000000); // Delay(100);
}

// -----------------------------------------------------------------------------------------------------------------------------

int main(void)
{
    // FPUEnable();
    // HWREG(0xE000ED88) |= (1<<20) | (1<<21) | (1<<22) | (1<<23);

    // Set up system clock
    SysCtlClockSet(SYSCTL_SYSDIV_2_5 | SYSCTL_USE_PLL | SYSCTL_OSC_MAIN | SYSCTL_XTAL_16MHZ); //80MHz


    // Initialization of uC Systems (GPIO, Timer, ADC, CAN)
    GPIO PinControl;
    PinControl.Init();

    ADC AnalogMeasurement;
    AnalogMeasurement.Init();

    TimerDelayInterruptBegin();

    // Initialization of CAN
    CAN BmsCanDriver;
    BmsCanDriver.init(PF0,PF3,1000000);
    unsigned int CANTIMERVALUE=0;
    unsigned int CANTIMERSTATUS=0;

    // enable the charge pump in FET Driver
    PinControl.chargePumpEnable();
    // enable the pack monitor in FET Driver
    PinControl.packMonitorEnable();

    // Visualization that BMS starts
    PinControl.pinEnable(LED_BASE, OK_LED, true);
    Delay(1000);  // delay 1s
    PinControl.pinEnable(LED_BASE, OK_LED, false);
    PinControl.pinEnable(LED_BASE, FAULT_LED, true);
    Delay(1000);  // delay 1s
    PinControl.pinEnable(LED_BASE, FAULT_LED, false);

    // Initialization of I2C (bq-chip)
    int error = BMS.Init(&Registers);

    // BMS system set up
    BMS.setShuntResistorValue(3);  // Shunt value 3mOhm
    BMS.setThermistorBetaValue(3428);  // B = 3428
    BMS.setTemperatureLimits(MIN_AFE_TEMPERATURE_DSG, MAX_AFE_TEMPERATURE_DSG, MIN_AFE_TEMPERATURE_CHG, MAX_AFE_TEMPERATURE_CHG);  // in ¢XC*10
    long shortcircuit_threshold_mA = BMS.setShortCircuitDischargeProtection(&Registers, SHORTCIRCUIT_SHUTDOWN, SHORTCIRCUIT_DELAY);
    long overcurrent_threshold_mA = BMS.setOvercurrentDischargeProtection(&Registers, OVERCURRENT_SHUTDOWN, OVERCURRENT_DELAY);
    int undervolt_threshold = BMS.setCellUndervoltageProtection(&Registers, UNDERVOLTAGE_SHUTDOWN, UNDERVOLTAGE_DELAY);
    int overvolt_threshold = BMS.setCellOvervoltageProtection(&Registers, OVERVOLTAGE_SHUTDOWN, OVERVOLTAGE_DELAY);
    SysCtlDelay(100000);
    // Set Balancing
    //  TODO ...

// -----------------------------------------------------------------------------------------------------------------------------
    /*
     * Option 1: Just turn both CHG and DSG on by using the update function in I2C class
     */
    TimerBMSUpdatesInterruptBegin(GlobalBMSUpdate);

// -----------------------------------------------------------------------------------------------------------------------------
    /*
     * Option 2: Depending on which mode we are in by comparing the Bat+ and Pack+, turn on the corresponding CHG or DSG funktion
     */

//    // Decide whether we are in Charge or Discharge mode by comparing the Bat+ and Pack+
//    if (batPlus > packPlus)
//    {
//        TimerBMSUpdatesInterruptBegin(GlobalBMSUpdateDSG);
//    }
//    else
//    {
//        TimerBMSUpdatesInterruptBegin(GlobalBMSUpdateCHG);
//    }

// -----------------------------------------------------------------------------------------------------------------------------

    // get the pack+ and bat+ voltage
    AnalogMeasurement.readVoltage();
    VoltageMeasurement voltage = AnalogMeasurement.getVoltageMeasurement();
    uint32_t packPlus = voltage.PackVoltage - voltage.cellGND;
    uint32_t batPlus = voltage.cellVoltage4 - voltage.cellGND;

    while(true)
    {
        // for testing and debugging use
        // BMS.update(&Registers);
        // Delay(200);  // delay 200ms (should be around 250 ms)


        // get the battery temperature
        AnalogMeasurement.readStackTemp();
        BatteryStackTemperature stackTemp = AnalogMeasurement.getBatteryStackTemperature();
        uint32_t temperature1 = stackTemp.temperature1;
        uint32_t temperature2 = stackTemp.temperature2;
        uint32_t temperature3 = stackTemp.temperature3;

        // get the MOSFETs temperature
        AnalogMeasurement.readMosfetTemp();
        MOSFETTemperature mosfetTemp = AnalogMeasurement.getMosfetTemperature();
        uint32_t DSGFetTemp = mosfetTemp.DSGFetTemp;
        uint32_t CHGFetTemp = mosfetTemp.CHGFetTemp;

        if (temperature1 > MAX_CELL_TMEPERATURE &&
            temperature2 > MAX_CELL_TMEPERATURE &&
            temperature3 > MAX_CELL_TMEPERATURE &&
            DSGFetTemp > MAX_FET_TEMPERATURE &&
            CHGFetTemp > MAX_FET_TEMPERATURE)

        {
            BMS.shutdown();
        }


        /*
         * CAN send out Message
         */

        // calculate the temperature back into celsius and convert into 8 bit integer
        uint8_t CanTemperatureBuffer[5];
        CanTemperatureBuffer[0] = (uint8_t) temperature1;
        CanTemperatureBuffer[1] = (uint8_t) temperature2;
        CanTemperatureBuffer[2] = (uint8_t) temperature3;
        CanTemperatureBuffer[3] = (uint8_t) DSGFetTemp;
        CanTemperatureBuffer[4] = (uint8_t) CHGFetTemp;
        // Send temperature
        BmsCanDriver.sendTemperature(CanTemperatureBuffer);



        int cell1 = BMS.getCellVoltage(1) / 100;
        int cell2 = BMS.getCellVoltage(2) / 100;
        int cell3 = BMS.getCellVoltage(3) / 100;
        int cell4 = BMS.getCellVoltage(4) / 100;

        // get the cell voltages and convert into 8 bit integer
        unsigned int CanVoltageBuffer[6] = {0};
        CanVoltageBuffer[0] = BMS.getCellVoltage(1) * 10;    // cell 1
        CanVoltageBuffer[1] = BMS.getCellVoltage(2) * 10;    // cell 2
        CanVoltageBuffer[2] = BMS.getCellVoltage(3) * 10;    // cell 3
        CanVoltageBuffer[3] = BMS.getCellVoltage(5) * 10;    // cell 4
        CanVoltageBuffer[4] = packPlus / 10;                 // pack+
        // Send Cell Voltage
        BmsCanDriver.sendVoltages(CanVoltageBuffer);

/*
        // In case we need backup voltage
        AnalogMeasurement.readVoltage();
        VoltageMeasurement voltage = AnalogMeasurement.getVoltageMeasurement();
        uint32_t packPlus = voltage.PackVoltage - voltage.cellGND;
        uint32_t cell1 = voltage.cellVoltage1 - voltage.cellGND;
        uint32_t cell2 = voltage.cellVoltage2 - voltage.cellVoltage1;
        uint32_t cell3 = voltage.cellVoltage3 - voltage.cellVoltage2;
        uint32_t cell4 = voltage.cellVoltage4 - voltage.cellVoltage3;
        uint32_t gnd = voltage.cellGND;
        SysCtlDelay(100000);
*/


    }
}

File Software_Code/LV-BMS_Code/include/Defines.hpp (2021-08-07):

/*
 * Defines.hpp
 *
 *  Created on: Feb 01, 2021
 *      Author: Dennis
 */

#ifndef INCLUDE_DEFINES_HPP_
#define INCLUDE_DEFINES_HPP_

// Voltage limit in mV or s
#define OVERVOLTAGE_SHUTDOWN                    42500   // max cell voltage 4,25 V
#define UNDERVOLTAGE_SHUTDOWN                   3000    // min cell voltage 3 V
#define OVER_TOTAL_VOLTAGE_SHUTDOWN             18000   // max total voltage 18 V
#define UNDER_TOTAL_VOLTAGE_SHUTDOWN            12000   // min total voltage 12 V
#define UNDERVOLTAGE_DELAY                      2       // delay 2 s
#define OVERVOLTAGE_DELAY                       2       // delay 2 s

// Current limit in mA or us
#define OVERCURRENT_SHUTDOWN                    30000   // max current 30 A
#define SHORTCIRCUIT_SHUTDOWN                   30000   // max shortcircuit current 30 A
#define OVERCURRENT_DELAY                       320     // delay 320 us
#define SHORTCIRCUIT_DELAY                      200     // delay 200 us

// Temperature limit in ¢XC*10
#define MAX_CELL_TMEPERATURE                    650     // max cell Temperature 65 Grad
#define MAX_FET_TEMPERATURE                     1000    // max FET Temperature 100 Grad
#define MAX_AFE_TEMPERATURE_CHG                 800     // max IC (AFE) charge temperature 80 grad
#define MAX_AFE_TEMPERATURE_DSG                 800     // max IC (AFE) discharge temperature 80 grad
#define MIN_AFE_TEMPERATURE_CHG                 0       // min IC (AFE) charge temperature 0 grad
#define MIN_AFE_TEMPERATURE_DSG                 0       // min IC (AFE) discharge temperature 0 grad

/*
// Balancing limit
#define OVER_BALANCING_TEMPERATURE_SHUTDOWN     500     // 50 Grad AFE-Chip Übertemperaturabschaltung beim Balancen
#define OVER_BALANCING_TEMPERATURE_WARNING      480     // 48 Grad AFE-Chip Übertemperaturwarnung beim Balancen
#define OVER_CELL_DIFFERENCE_SHUTDOWN           5000    // Wird nicht verwendet
#define OVER_CELL_DIFFERENCE_WARNING            2000    // Wird nicht verwendet

#define BALANCE_RESTRICT                        29800   // Nur wenn die niedrigste Spannung da drüber ist, lässt sich das Balancen starten
#define BALANCING_CYCLE_TIME_SEC                10

#define CAN_MESSAGE_BALANCE_REQUEST_BIT       0
#define CAN_MESSAGE_SHUTDOWN_BIT              1
#define CAN_MESSAGE_VOLTAGES              0x701
#define CAN_MESSAGE_TEMP_AFE              0x704
#define CAN_MESSAGE_TEMP_CELL             0x70C
#define CAN_MESSAGE_STATUS                0x709
#define CAN_MESSAGE_STACK_INFO            0x70A
#define CAN_MESSAGE_ERROR                 0x708
#define CAN_MESSAGE_Control_LVBMS_STATUS  0x705
#define CAN_MESSAGE_CONTROL_AFE_IN        0x70B
*/



#endif /* INCLUDE_DEFINES_HPP_ */

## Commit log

2021-08-07 Upload Altium design and c++ code
    upload the hardware altium PCB design of the LV-BMS and software code written in c++ for the microcontroller. The code is written in code composer studio for debugging and flashing in microcontroller
    [ADC.obj, AFE_BQ-Chip.SchDoc, BQ76200PW.PcbLib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]
2021-08-11 update readme and add BMS_version1 image
    [BOM_LV_21E.xlsx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]
2021-08-11 update the concept and functionality of lv-bms in readme
2021-08-15 update I2C in readme
2021-08-15 update ADC and FET driver in hardware readme
2021-08-15 update adc function in readme
2021-08-17 add PCB polygon image
